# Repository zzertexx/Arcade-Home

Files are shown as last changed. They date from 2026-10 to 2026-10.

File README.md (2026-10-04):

# Arcade@Home
Console with games, outputting HDMI and Joysticks to control it

## What is it?
It is a combo of joysticks and main console which offers pixel games to play in multiplayer on any display with HDMI

## Why did I build it?
I saw that a lot of people did tamagotchi during their way, so I wanted to do similar but ended at gaming console 
I took my little bro with me to teach him hardware

## How to recreate it?
1. Order both PCBs
2. 3D Print enclosures
3. Assemble hardware
4. Flush Firmware(not ready yet)
5. Connect HDMI
6. Play!

## Future Plans:
* Enclosure for Joystick
* Firmware for ESP32
* Firmware for 

## Bill of Materials
| Name | Price |
| --- | --- |
| XUNPU HDMI-001S | 0.25$ |
| RP2350A | 1.3$ |
| JST 3 pin | 0.1$ |
| onsemi NCP1117 3.3V DPO | 0.25$ |
| Flash Memory W25Q128JVSIQ | 2.6$ |
| Tactile Button x2 | 0.04$ |
| Type C x2 | 1.5$ |
| Pi Radio Module 2 | 5.00$ |
| +1v1 buck | 0,4$ |
| Green LED 0603 x2 | 0.02$ |
| Header Pins | 0.15$ |
| SS34 | 0,03$ |
| 4.7uF 0603 x3 | 0.1$ |
| 100nF 0603 x14 | 0.12$ |
| 10uF 0805 x3 | 0.12$ |
| 15pF 0402 x2 | 0.04$ |
| 3.3uH 0806 | 0.3$ |
| 2.2uH | 0.1$ |
| 27R 0603 x2 | 0.00$ |
| 33R 0603 | 0.00$ |
| 5.1KR 0603 x2 | 0.00$ | 
| 220R x5 | 0.01$ |
| 270R 0603 x9 | 0.02$ |
| 1K 0603 x6 | 0.01$ |
| 1.2K | 0.01$ |
| 4.7K x2 | 0.01$ |
| 10K 0603 x2 | 0.01$ |
| 100R 0603 x3 | 0.00$ |
| 470R 0603 x2 | 0.01$ |
| 120K 0603 | 0.00$ | 
| 100K 0603 | 0.00$ | 
| Push Button x4 | 4.24$ |
| ESP32 - SuperMini | 2.00$ |
| Turn-ON Button | 1.3$ |
| Microswitch x4 | 2$ |
| TP4056 | 0.09$ |
| FS8205A | 0.06$ |
| DW01A | 0.03$ |
| Total | 8.6$ |

## Images



arcade_console (Assembly)

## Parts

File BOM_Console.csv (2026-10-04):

Arcade Console PCB
Name | Quantity | Price | Number | Link
XUNPU HDMI-001S | 1 | $0,25 | C720616 | https://www.lcsc.com/product-image/C720616.html?whichImg=sch
RP2350A | 1 | $1,30 | C42411118 | https://www.lcsc.com/product-detail/C42411118.html?s_z=n_q_t_rp2350
JST 3 pin TXM12M... | 1 | $0,10 | C284155 | https://www.lcsc.com/product-detail/C284155.html?s_z=n_q_12MHz%2520Crystal
onsemi NCP1117 3.3V DPO | 1 | $0,25 | C26537 | https://www.lcsc.com/product-detail/C26537.html
Flash Memory W25Q128JVSIQ | 1 | $2,60 | C97521 | https://www.lcsc.com/product-detail/C97521.html
Tactile Button | 2 | $0,04 | C53447020 | https://www.lcsc.com/product-detail/C53447020.html?s_z=n_q_tactile%2520button
Type C | 1 | $0,85 | C5409177 | https://www.lcsc.com/product-detail/C5409177.html
Pi Radio Module 2 | 1 | $5,00 |  | https://www.alibaba.com/product-detail/Raspberry-Pi-Original-Wireless-Module-Supports_1601564887233.html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
1v1 buck | 1 | $0,40 | C141836 | https://www.lcsc.com/product-detail/C141836.html?s_z=n_q_TLV62569%2520
Green LED 0603 | 2 | $0,02 | C7371905 | https://www.lcsc.com/product-detail/C7371905.html?s_z=n_q_t_LED
Header Pins | 1 | $0,15 | C2337 | https://www.lcsc.com/product-detail/C2337.html?s_z=n_q_t_pin%2520header
SS34 | 1 | $0,03 | C5380710 | https://www.lcsc.com/product-detail/C5380710.html?s_z=n_q_t_SS34
Capacitors
4.7uF 0603 | 3 | $0,10 | C20539423 | https://www.lcsc.com/product-detail/C20539423.html?s_z=n_q_t_CAPACITORS
100nF 0603 | 12 | $0,12 | C1590 | https://www.lcsc.com/product-detail/C1590.html?s_z=n_q_t_CAPACITORS
10uF 0805 | 2 | $0,12 | C15850 | https://www.lcsc.com/product-detail/C15850.html?s_z=n_q_t_CAPACITORS
15pF 0402 | 2 | $0,04 | C441742 | https://www.lcsc.com/product-detail/C441742.html?s_z=n_q_t_CAPACITORS
Inductor
3.3uH 0806 | 1 | $0,30 | C42411119 | https://www.lcsc.com/product-detail/C42411119.html
2.2uH | 1 | $0,10 | C7427146 | https://www.lcsc.com/product-detail/C7427146.html
Resistors
27 ohm 0603 | 2 | $0,00 | C2907021 | https://www.lcsc.com/product-detail/C2907021.html
33 ohm 0603 | 1 | $0,00 | C2909394 | https://www.lcsc.com/product-detail/C2909394.html
5.1K 0603 | 2 | $0,00 | C2907044 | https://www.lcsc.com/product-detail/C2907044.html
270R 0603 | 9 | $0,02 | C22966 | https://www.lcsc.com/product-detail/C22966.html
1K 0603 | 3 | $0,01 | C22548 | https://www.lcsc.com/product-detail/C22548.html
10K 0603 | 2 | $0,01 | C98220 | https://www.lcsc.com/product-detail/C98220.html
100R 0603 | 2 | $0,00 | C2906981 | https://www.lcsc.com/product-detail/C2906981.html
470R 0603 | 2 | $0,01 | C23179 | https://www.lcsc.com/product-detail/C23179.html
120K 0603 | 1 | $0,00 | C25808 | https://www.lcsc.com/product-detail/C25808.html
100K 0603 | 1 | $0,00 | C14675 | https://www.lcsc.com/product-detail/C14675.html

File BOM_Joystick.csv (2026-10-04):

ARCADE
Name | Quantity | Price | Link
Push Button | 4 | $4,24 | https://aliexpress.ru/item/1005008849653398.html?gatewayAdapt=glo2rus&sku_id=12000046936327681
Turn-ON Button | 1 | $1,30 | https://www.lcsc.com/product-detail/C48677982.html?s_z=n_q_t_BUTTON
4,7k resistor | 2 | $0,01 | https://www.lcsc.com/product-detail/C99782.html?s_z=n_q_t_resistor%2520
100nf capacitor | 2 | $0,02 | https://www.lcsc.com/product-detail/C14663.html?s_z=n_q_t_%2520Capacitors
10uf capacitor | 1 | $0,04 | https://www.lcsc.com/product-detail/C19702.html?s_z=n_q_t_%2520Capacitors
220 om resistor | 5 | $0,01 | https://www.lcsc.com/product-detail/C22962.html?s_z=n_q_t_resistor
1k resistor | 3 | $0,01 | https://www.lcsc.com/product-detail/C22548.html?s_z=n_q_t_resistor
100 resistor | 1 | $0,01 | https://www.lcsc.com/product-detail/C2906981.html?s_z=n_q_t_resistor
1,2k resistor | 1 | $0,01 | https://www.lcsc.com/product-detail/C114605.html?s_z=n_q_t_resistor
pin header 2,54mm | 1 |  | https://www.lcsc.com/product-detail/C2691448.html?s_z=n_q_t_pin%2520header%25202.54mm
Tp4056 | 1 | $0,09 | https://www.lcsc.com/product-detail/C725790.html?s_z=n_q_tp4056
fs8205A | 1 | $0,06 | https://www.lcsc.com/product-detail/C2830320.html?s_z=s_p_FS8205A
dw01A | 1 | $0,03 | https://www.lcsc.com/product-detail/C351410.html?s_z=s_p_DW01A
Type C | 1 | $0,90 | https://www.lcsc.com/product-detail/C5409177.html?s_z=s_p_10155435-00011LF
Microswitch(joystick) | 4 | $2,00 | https://www.alibaba.com/product-detail/Factory-High-quality-Micro-Switches-for_1601206239153.html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
ESP32-Supermini | 1 | $1,75 | https://aliexpress.ru/item/1005006685958843.html?sku_id=12000038011863174

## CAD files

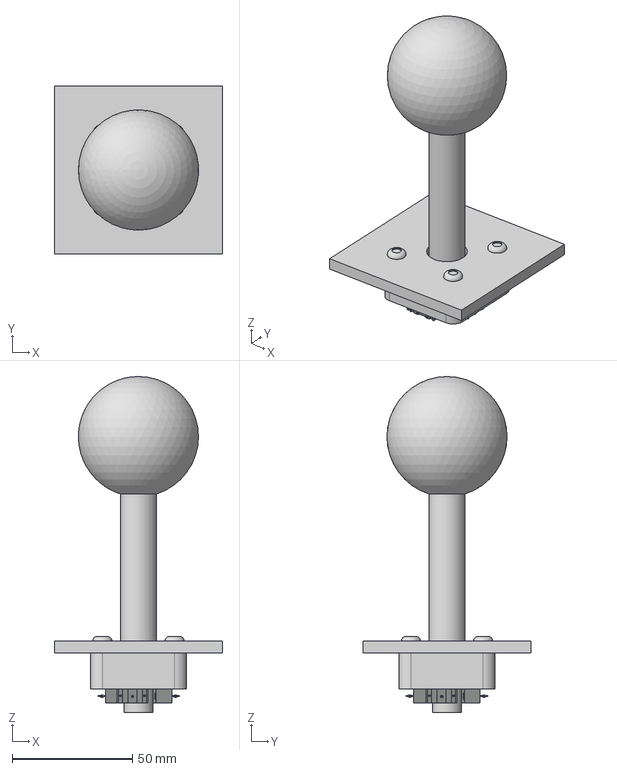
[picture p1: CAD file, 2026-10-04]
CAD/joystick.step
70.0 x 70.0 x 139.7 mm

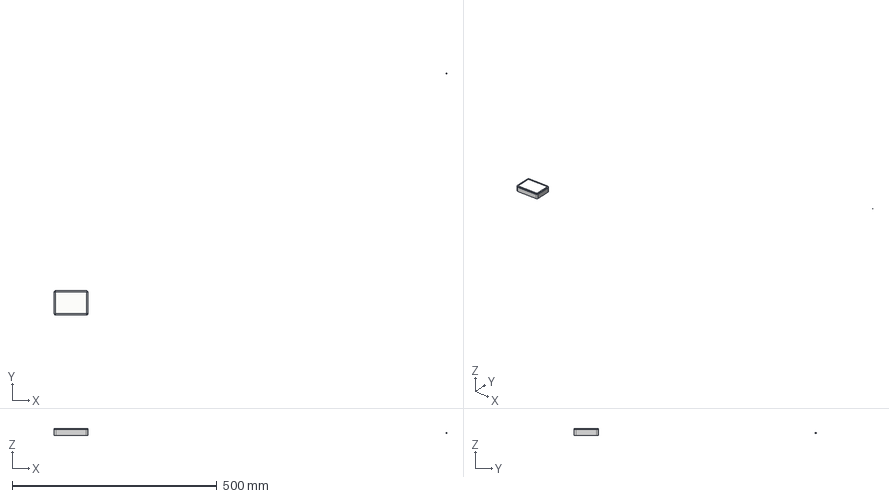
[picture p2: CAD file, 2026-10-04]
CAD/console.step
958.9 x 591.6 x 18.0 mm

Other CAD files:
CAD/console.f3z
CAD/joystick.f3z

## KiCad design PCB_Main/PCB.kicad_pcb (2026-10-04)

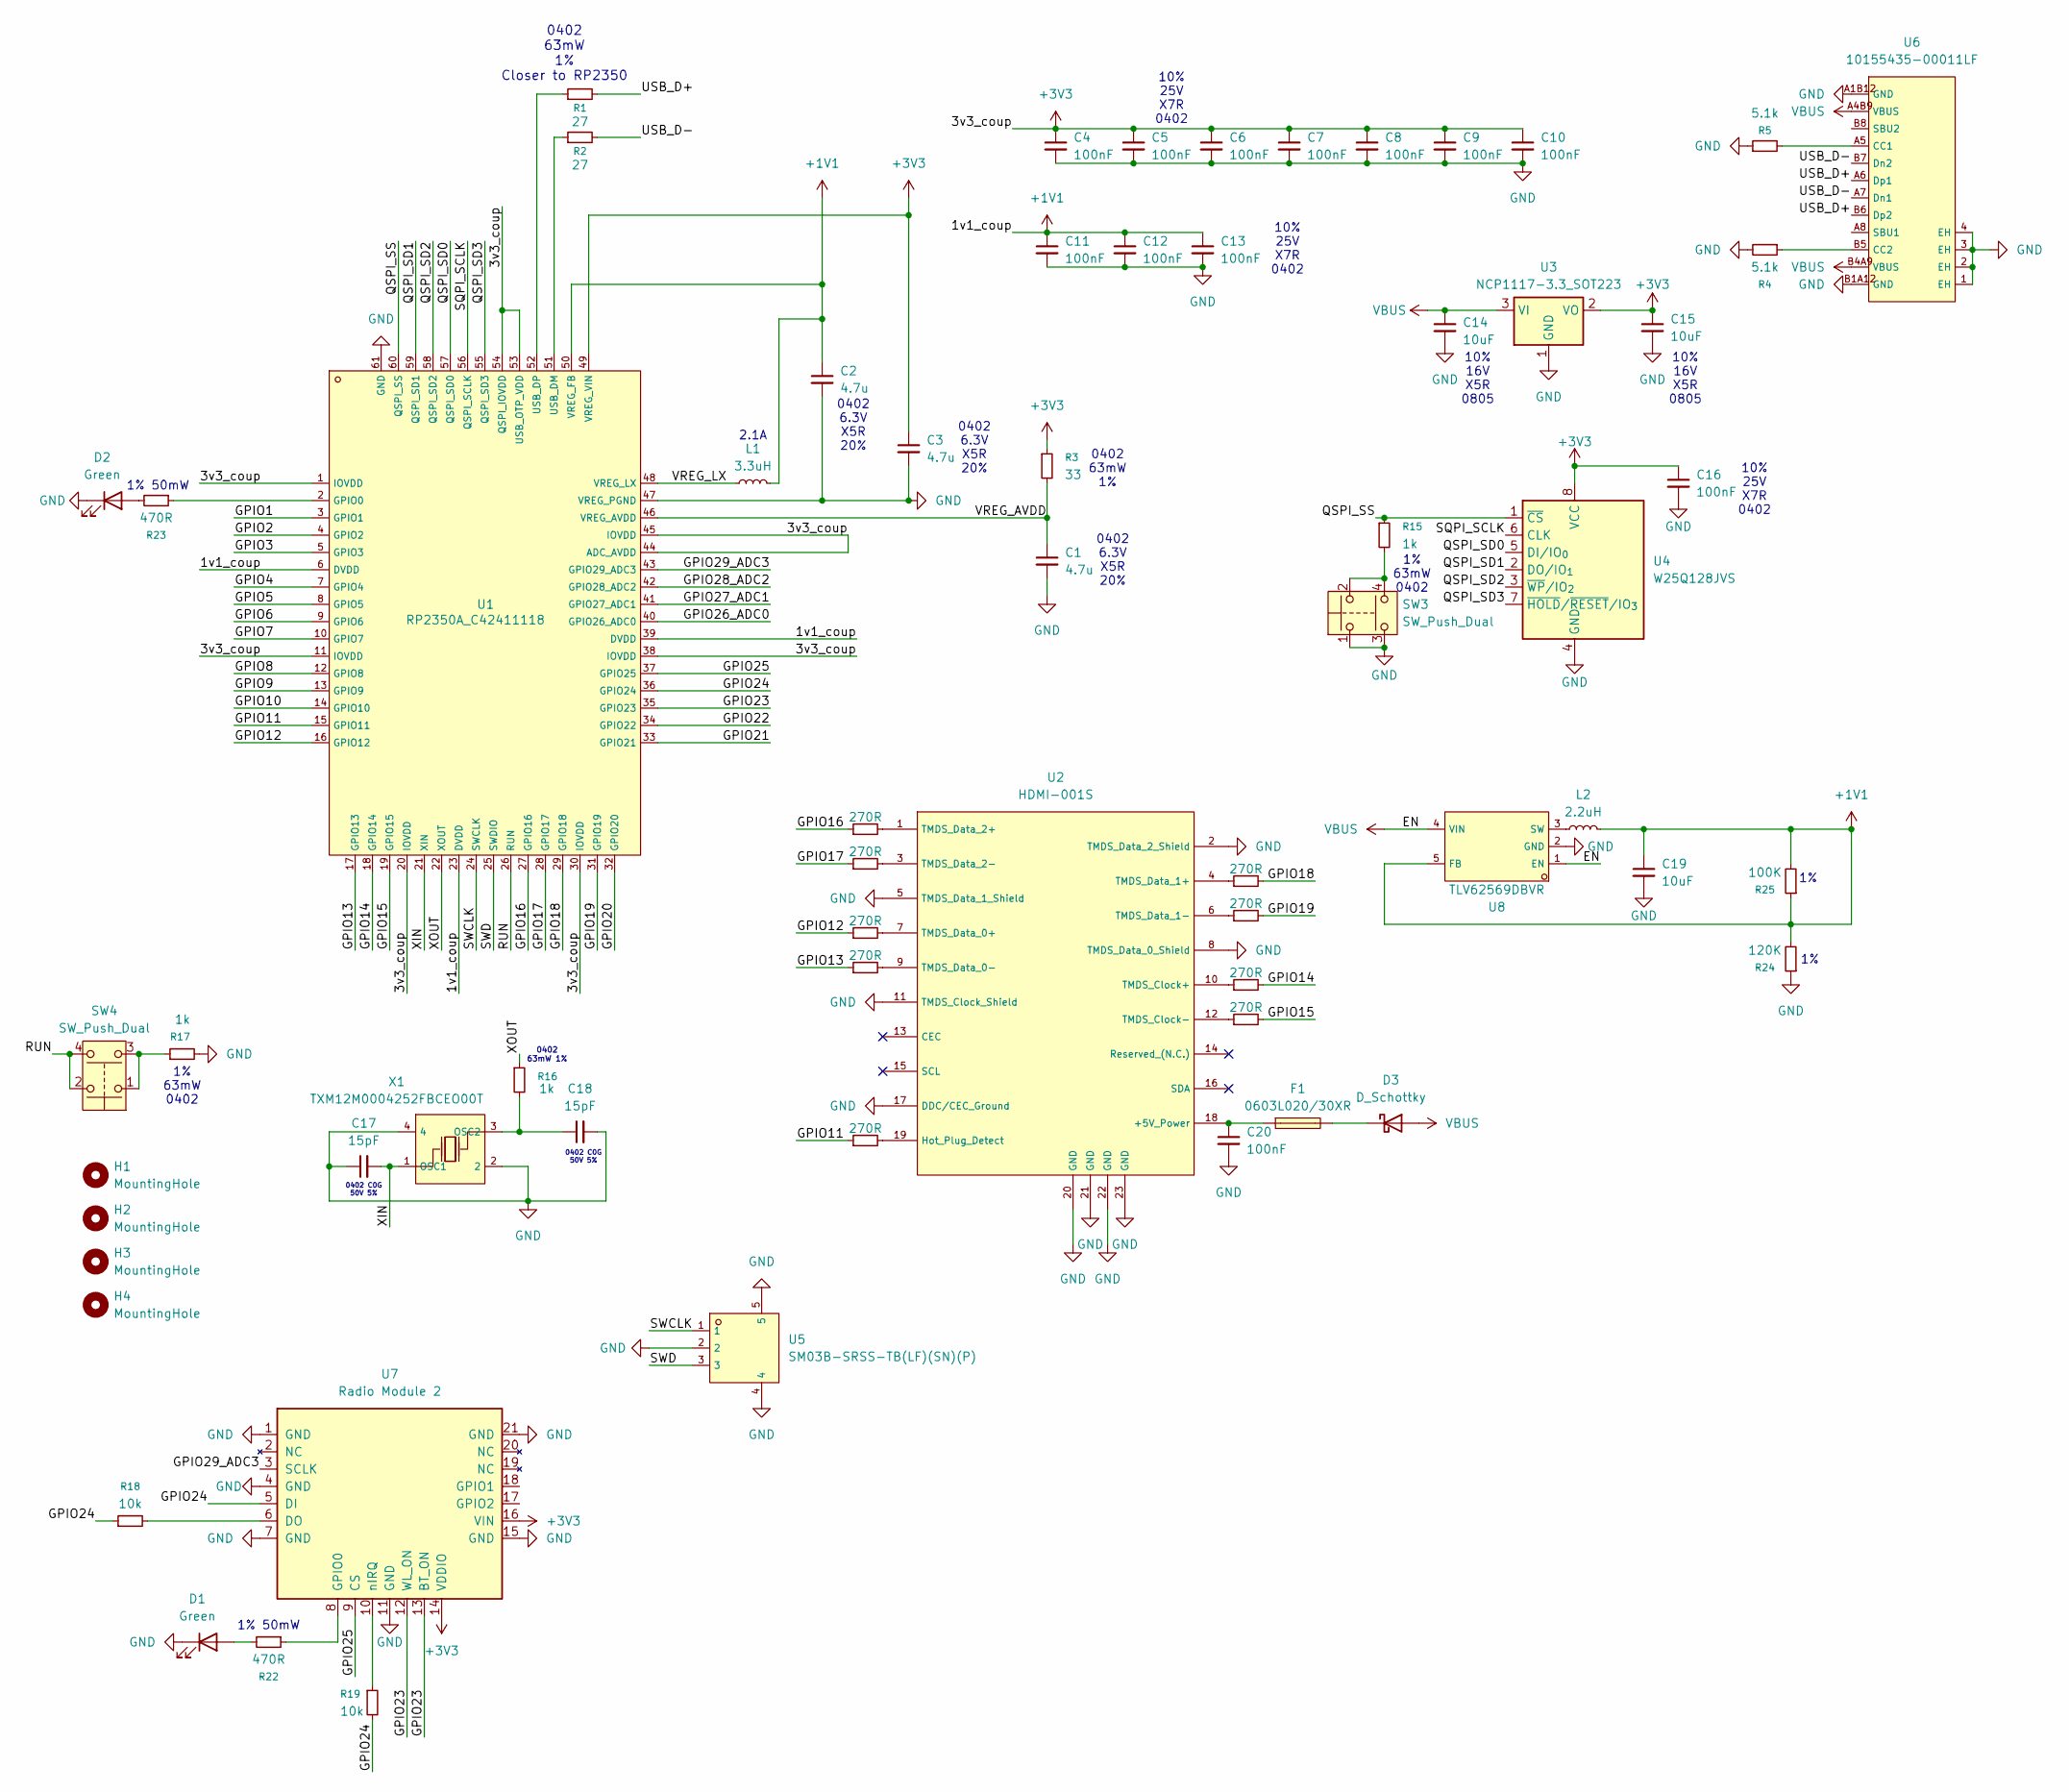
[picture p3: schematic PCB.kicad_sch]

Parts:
C1, C2, C3: 4.7u; C_0603_1608Metric_Pad1.08x0.95mm_HandSolder
C4, C5, C6, C7, C8, C9, C10, C11, C12, C13, C16, C20: 100nF; C_0603_1608Metric_Pad1.08x0.95mm_HandSolder
C14, C15, C19: 10uF; C_0805_2012Metric_Pad1.18x1.45mm_HandSolder
C17, C18: 15pF; C_0402_1005Metric_Pad0.74x0.62mm_HandSolder
D1, D2: Green; LED_0603_1608Metric_Pad1.05x0.95mm_HandSolder
D3: D_Schottky; D_SOD-123
F1: 0603L020/30XR; F0603; LCSC C20608677
H1, H2, H3, H4: MountingHole; MountingHole_2.5mm
L1: 3.3uH; IND-SMD_L2.0-W1.6_AOTA-B201610S3R3-101-T
L2: 2.2uH; L_APV_ANR6028
R1, R2: 27; R_0603_1608Metric_Pad0.98x0.95mm_HandSolder
R3: 33; R_0603_1608Metric_Pad0.98x0.95mm_HandSolder
R4, R5: 5.1k; R_0603_1608Metric_Pad0.98x0.95mm_HandSolder
R6, R7, R8, R9, R10, R11, R12, R13, R14: 270R; R_0603_1608Metric_Pad0.98x0.95mm_HandSolder
R15, R16, R17: 1k; R_0603_1608Metric_Pad0.98x0.95mm_HandSolder
R18, R19: 10k; R_0603_1608Metric_Pad0.98x0.95mm_HandSolder
R22, R23: 470R; R_0603_1608Metric_Pad0.98x0.95mm_HandSolder
R24: 120K; R_0603_1608Metric_Pad0.98x0.95mm_HandSolder
R25: 100K; R_0603_1608Metric_Pad0.98x0.95mm_HandSolder
SW3, SW4: SW_Push_Dual; SW-SMD_4P-L6.0-W6.0-P4.50-LS7.2
U1: RP2350A_C42411118; QFN-60_L7.0-W7.0-P0.40-TL-EP3.4; LCSC C42411118
U2: HDMI-001S; HDMI-SMD_HDMI-001S; LCSC C720616
U3: NCP1117-3.3_SOT223; SOT-223-3_TabPin2
U4: W25Q128JVS; SOIC-8_5.3x5.3mm_P1.27mm
U5: SM03B-SRSS-TB(LF)(SN)(P); CONN-SMD_SM03B-SRSS-TB-LF-SN-P; LCSC C160403
U6: 10155435-00011LF; USB-C-SMD_10155435-00011LF; LCSC C5409177
U7: Radio Module 2; rpi_rmc20452t
U8: TLV62569DBVR; SOT-23-5_L3.0-W1.7-P0.95-LS2.8-BR; LCSC C141836
X1: TXM12M0004252FBCEO00T; OSC-SMD_4P-L2.5-W2.0-BL; LCSC C284155

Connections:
+1V1: C2.1, C11.1, C12.1, C13.1, C19.1, L1.2, L2.2, R24.2, R25.1, R25.2, U1.6 (DVDD), U1.23 (DVDD), U1.39 (DVDD), U1.50 (VREG_FB), U8.5 (FB)
+3V3: C3.1, C4.1, C5.1, C6.1, C7.1, C8.1, C9.1, C10.1, C15.1, C16.1, R3.1, U1.1 (IOVDD), U1.11 (IOVDD), U1.20 (IOVDD), U1.30 (IOVDD), U1.38 (IOVDD), U1.44 (ADC_AVDD), U1.45 (IOVDD), U1.49 (VREG_VIN), U1.53 (USB_OTP_VDD), U1.54 (QSPI_IOVDD), U3.2 (VO), U4.8 (VCC), U7.14 (VDDIO), U7.16 (VIN)
/GPIO1: U1.3 (GPIO1)
/GPIO2: U1.4 (GPIO2)
/GPIO3: U1.5 (GPIO3)
/GPIO4: U1.7 (GPIO4)
/GPIO5: U1.8 (GPIO5)
/GPIO6: U1.9 (GPIO6)
/GPIO7: U1.10 (GPIO7)
/GPIO8: U1.12 (GPIO8)
/GPIO9: U1.13 (GPIO9)
/GPIO10: U1.14 (GPIO10)
/GPIO11: R14.1, U1.15 (GPIO11)
/GPIO12: R10.1, U1.16 (GPIO12)
/GPIO13: R11.1, U1.17 (GPIO13)
/GPIO14: R12.2, U1.18 (GPIO14)
/GPIO15: R13.2, U1.19 (GPIO15)
/GPIO16: R6.1, U1.27 (GPIO16)
/GPIO17: R7.1, U1.28 (GPIO17)
/GPIO18: R8.2, U1.29 (GPIO18)
/GPIO19: R9.2, U1.31 (GPIO19)
/GPIO20: U1.32 (GPIO20)
/GPIO21: U1.33 (GPIO21)
/GPIO22: U1.34 (GPIO22)
/GPIO23: U1.35 (GPIO23), U7.12 (WL_ON), U7.13 (BT_ON)
/GPIO24: R18.1, R19.2, U1.36 (GPIO24), U7.5 (DI)
/GPIO25: U1.37 (GPIO25), U7.9 (CS)
/GPIO26_ADC0: U1.40 (GPIO26_ADC0)
/GPIO27_ADC1: U1.41 (GPIO27_ADC1)
/GPIO28_ADC2: U1.42 (GPIO28_ADC2)
/GPIO29_ADC3: U1.43 (GPIO29_ADC3), U7.3 (SCLK)
/QSPI_SD0: U1.57 (QSPI_SD0), U4.5 (DI/IO_{0})
/QSPI_SD1: U1.59 (QSPI_SD1), U4.2 (DO/IO_{1})
/QSPI_SD2: U1.58 (QSPI_SD2), U4.3 (~WP/IO_{2})
/QSPI_SD3: U1.55 (QSPI_SD3), U4.7 (~HOLD/~RESET/IO_{3})
/QSPI_SS: R15.1, U1.60 (QSPI_SS), U4.1 (~CS)
/RUN: SW4.2, SW4.4, U1.26 (RUN)
/SQPI_SCLK: U1.56 (QSPI_SCLK), U4.6 (CLK)
/SWCLK: U1.24 (SWCLK), U5.1
/SWD: U1.25 (SWDIO), U5.3
/USB_D+: R1.2, U6.A6 (Dp1), U6.B6 (Dp2)
/USB_D-: R2.2, U6.A7 (Dn1), U6.B7 (Dn2)
/VREG_AVDD: C1.1, R3.2, U1.46 (VREG_AVDD)
/VREG_LX: L1.1, U1.48 (VREG_LX)
/XIN: C17.2, U1.21 (XIN), X1.1 (OSC1)
/XOUT: R16.1, U1.22 (XOUT)
GND: C1.2, C2.2, C3.2, C4.2, C5.2, C6.2, C7.2, C8.2, C9.2, C10.2, C11.2, C12.2, C13.2, C14.2, C15.2, C16.2, C17.1, C18.2, C19.2, C20.2, D1.1 (K), D2.1 (K), R4.2, R5.1, R17.2, R24.1, SW3.1, SW3.3, U1.47 (VREG_PGND), U1.61 (GND), U2.2 (TMDS_Data_2_Shield), U2.5 (TMDS_Data_1_Shield), U2.8 (TMDS_Data_0_Shield), U2.11 (TMDS_Clock_Shield), U2.17 (DDC/CEC_Ground), U2.20 (GND), U2.21 (GND), U2.22 (GND), U2.23 (GND), U3.1 (GND), U4.4 (GND), U5.2, U5.4, U5.5, U6.1 (EH), U6.2 (EH), U6.3 (EH), U6.4 (EH), U6.A1B12 (GND), U6.B1A12 (GND), U7.1 (GND), U7.4 (GND), U7.7 (GND), U7.11 (GND), U7.15 (GND), U7.21 (GND), U8.2 (GND), X1.2, X1.4
unnamed: D1.2 (A), R22.2
unnamed: D2.2 (A), R23.2
unnamed: D3.1 (K), F1.2
unnamed: R15.2, SW3.2, SW3.4
unnamed: R17.1, SW4.1, SW4.3
unnamed: R23.1, U1.2 (GPIO0)
unnamed: R2.1, U1.51 (USB_DM)
unnamed: R1.1, U1.52 (USB_DP)
unnamed: C20.1, F1.1, U2.18 (+5V_Power)
unnamed: R14.2, U2.19 (Hot_Plug_Detect)
unnamed: R12.1, U2.10 (TMDS_Clock+)
unnamed: R13.1, U2.12 (TMDS_Clock-)
unnamed: R10.2, U2.7 (TMDS_Data_0+)
unnamed: R11.2, U2.9 (TMDS_Data_0-)
unnamed: R8.1, U2.4 (TMDS_Data_1+)
unnamed: R9.1, U2.6 (TMDS_Data_1-)
unnamed: R6.2, U2.1 (TMDS_Data_2+)
unnamed: R7.2, U2.3 (TMDS_Data_2-)
unnamed: R5.2, U6.A5 (CC1)
unnamed: R4.1, U6.B5 (CC2)
unnamed: R18.2, U7.6 (DO)
unnamed: R22.1, U7.8 (GPIO0)
unnamed: R19.1, U7.10 (nIRQ)
unnamed: L2.1, U8.3 (SW)
unnamed: C18.1, R16.2, X1.3 (OSC2)
VBUS: C14.1, D3.2 (A), U3.3 (VI), U6.A4B9 (VBUS), U6.B4A9 (VBUS), U8.1 (EN), U8.4 (VIN)

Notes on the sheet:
0402 63mW 1% Closer to RP2350
1% 50mW
0402 6.3V X5R 20%
10% 16V X5R 0805
0402 63mW 1%
10% 25V X7R 0402
0402 63mW 1%
1% 63mW 0402
0402 C0G 50V 5%
2.1A

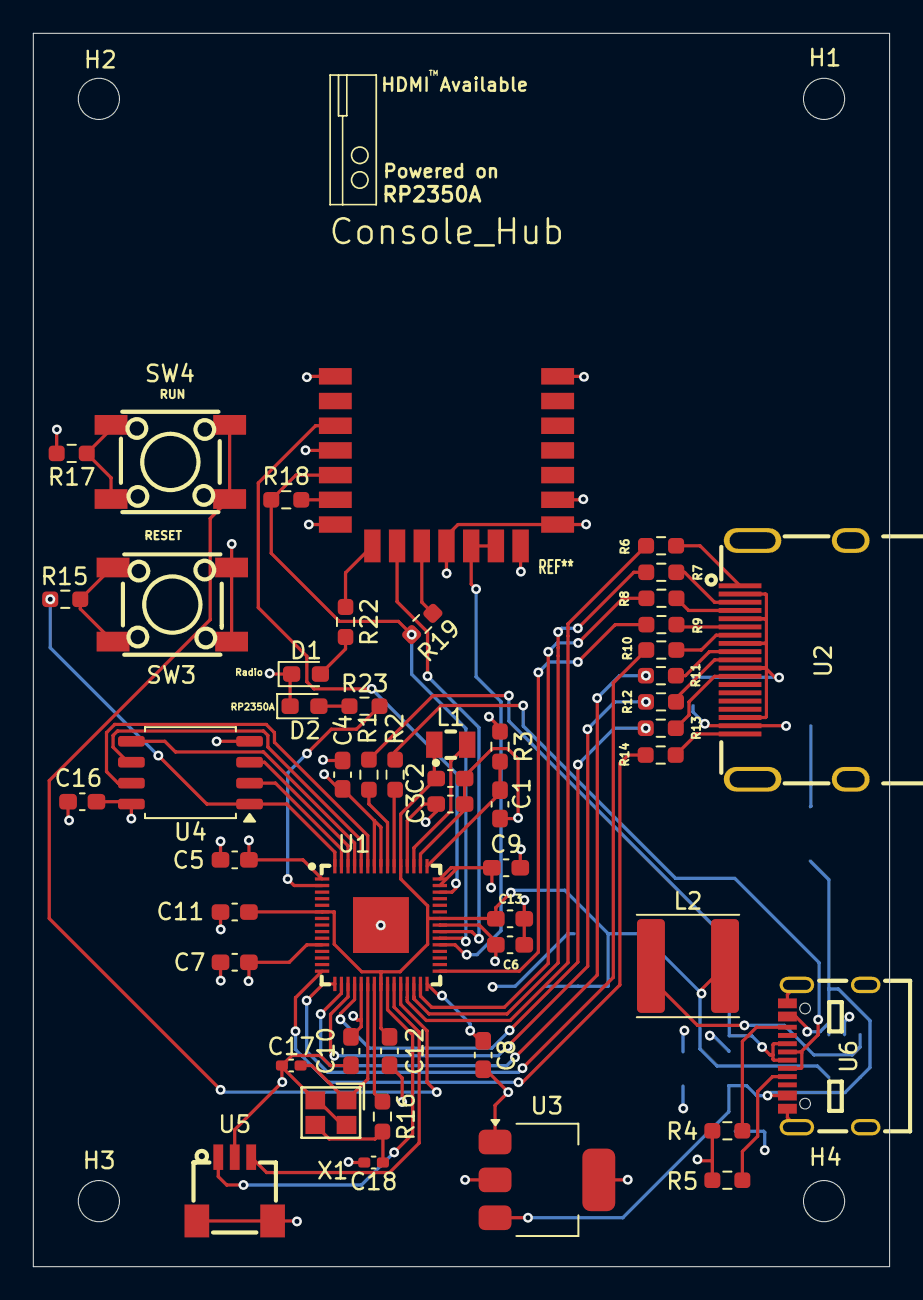
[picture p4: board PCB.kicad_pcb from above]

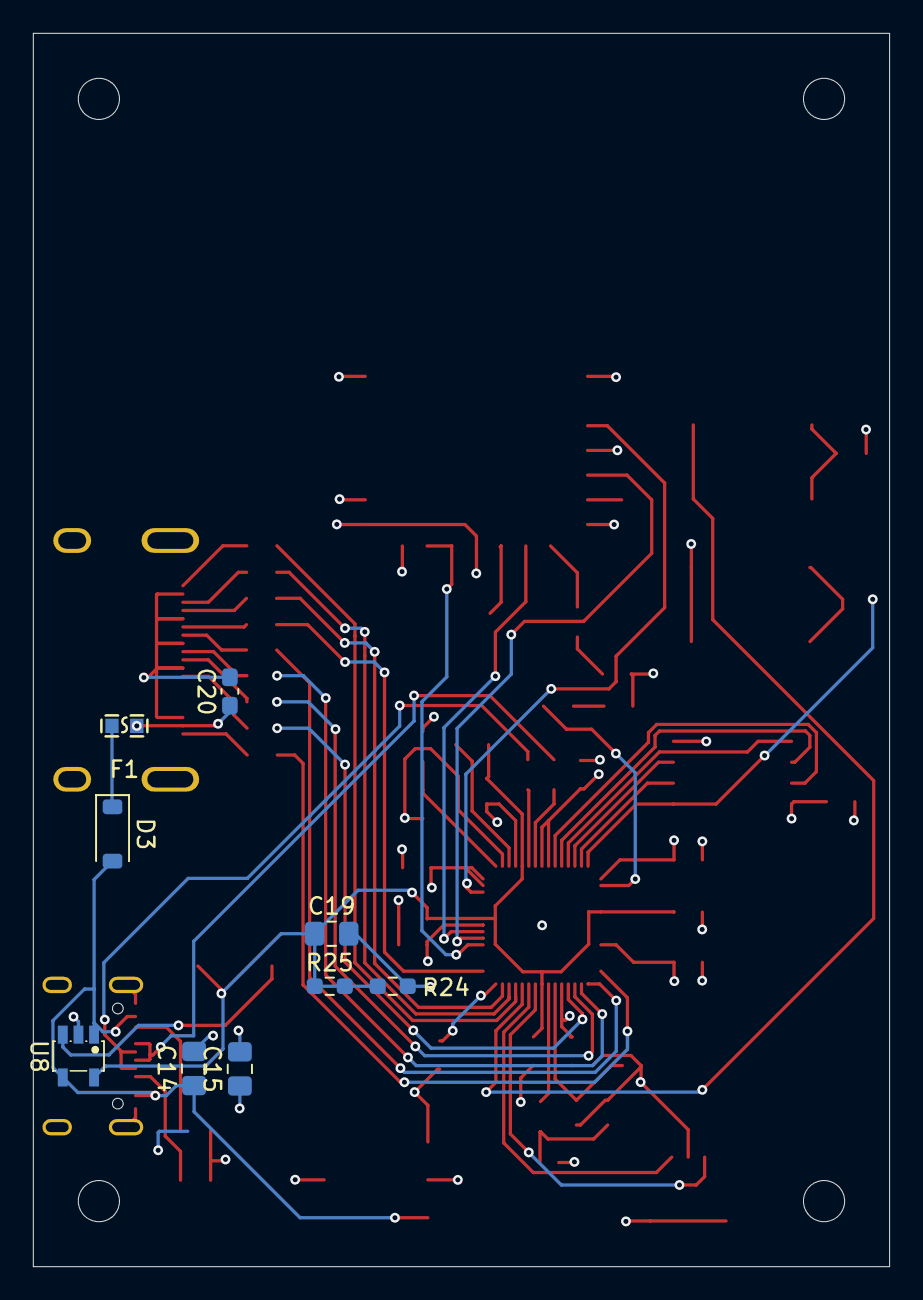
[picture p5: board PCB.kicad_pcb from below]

Board: 4 copper layers, 52.0 x 74.9 mm, 64 parts (9 on the bottom side), 57 nets.

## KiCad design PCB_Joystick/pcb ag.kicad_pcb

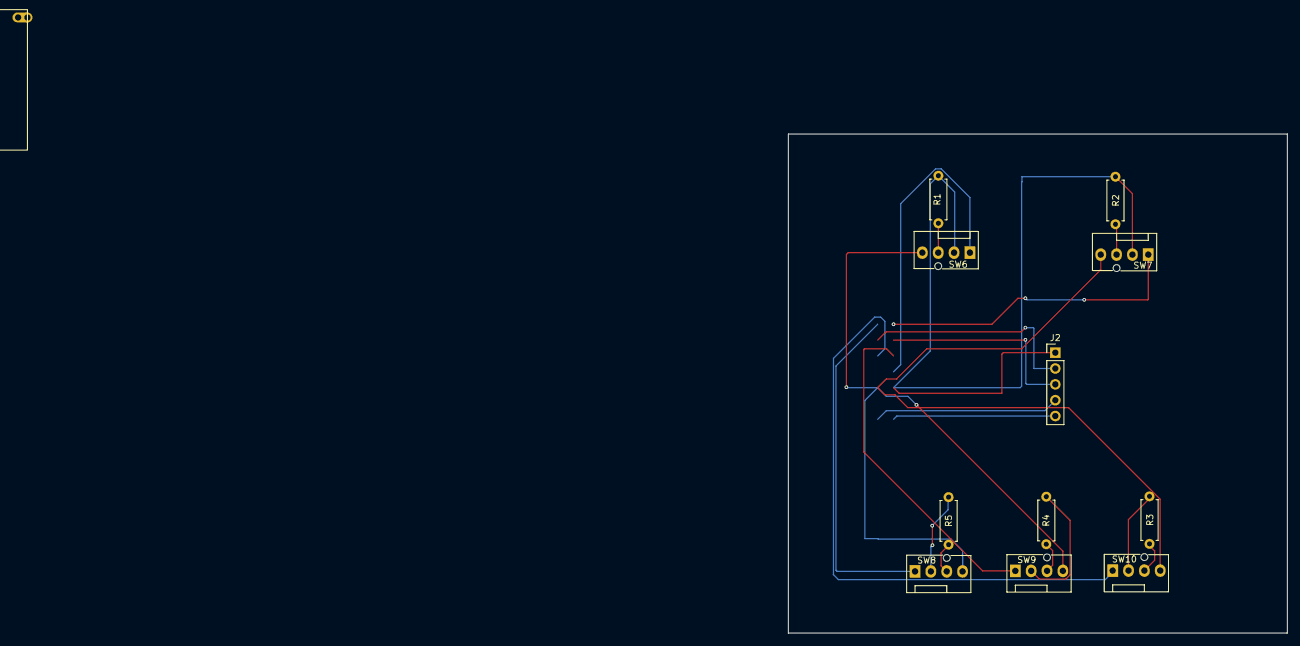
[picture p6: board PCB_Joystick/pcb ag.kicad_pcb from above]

Board: 2 copper layers, 80.0 x 80.0 mm, 12 parts (0 on the bottom side), 8 nets.

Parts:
J2: Conn_01x05; PinHeader_1x05_P2.54mm_Vertical
R1, R2: 220ом; R_Axial_DIN0207_L6.3mm_D2.5mm_P7.62mm_Horizontal
R3, R4, R5: 220; R_Axial_DIN0207_L6.3mm_D2.5mm_P7.62mm_Horizontal
SW6, SW7, SW8, SW9, SW10: SW_Push_LED; FanPinHeader_1x04_P2.54mm_Vertical
U1: ESP32-C3-Supermini

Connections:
+3V3: SW6.4 (A), SW7.4 (A), SW8.4 (A), SW9.4 (A), SW10.4 (A)
/2button.gpio6: SW7.1, U1.1 (GPIO6_1)
GND: J2.1, R1.2, R2.2, R3.2, R4.2, R5.2, SW6.2, SW7.2, SW8.2, SW9.2, SW10.2
unnamed: R1.1, SW6.3 (K)
unnamed: R2.1, SW7.3 (K)
unnamed: R5.1, SW8.3 (K)
unnamed: R4.1, SW9.3 (K)
unnamed: R3.1, SW10.3 (K)

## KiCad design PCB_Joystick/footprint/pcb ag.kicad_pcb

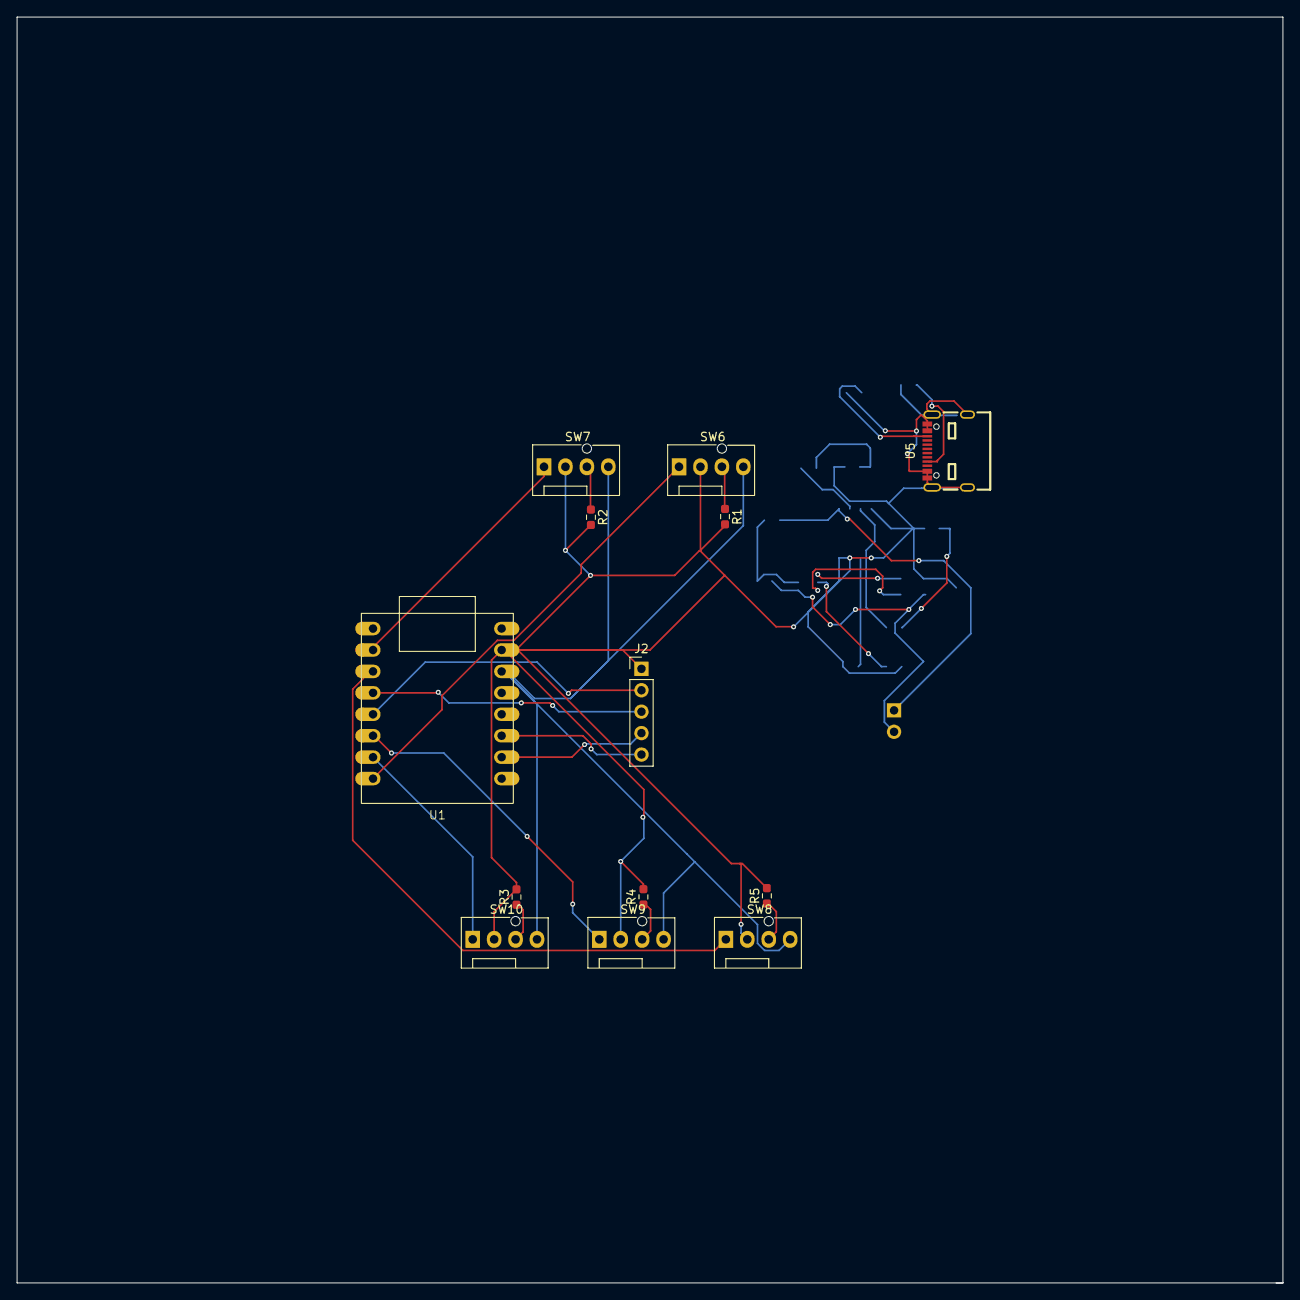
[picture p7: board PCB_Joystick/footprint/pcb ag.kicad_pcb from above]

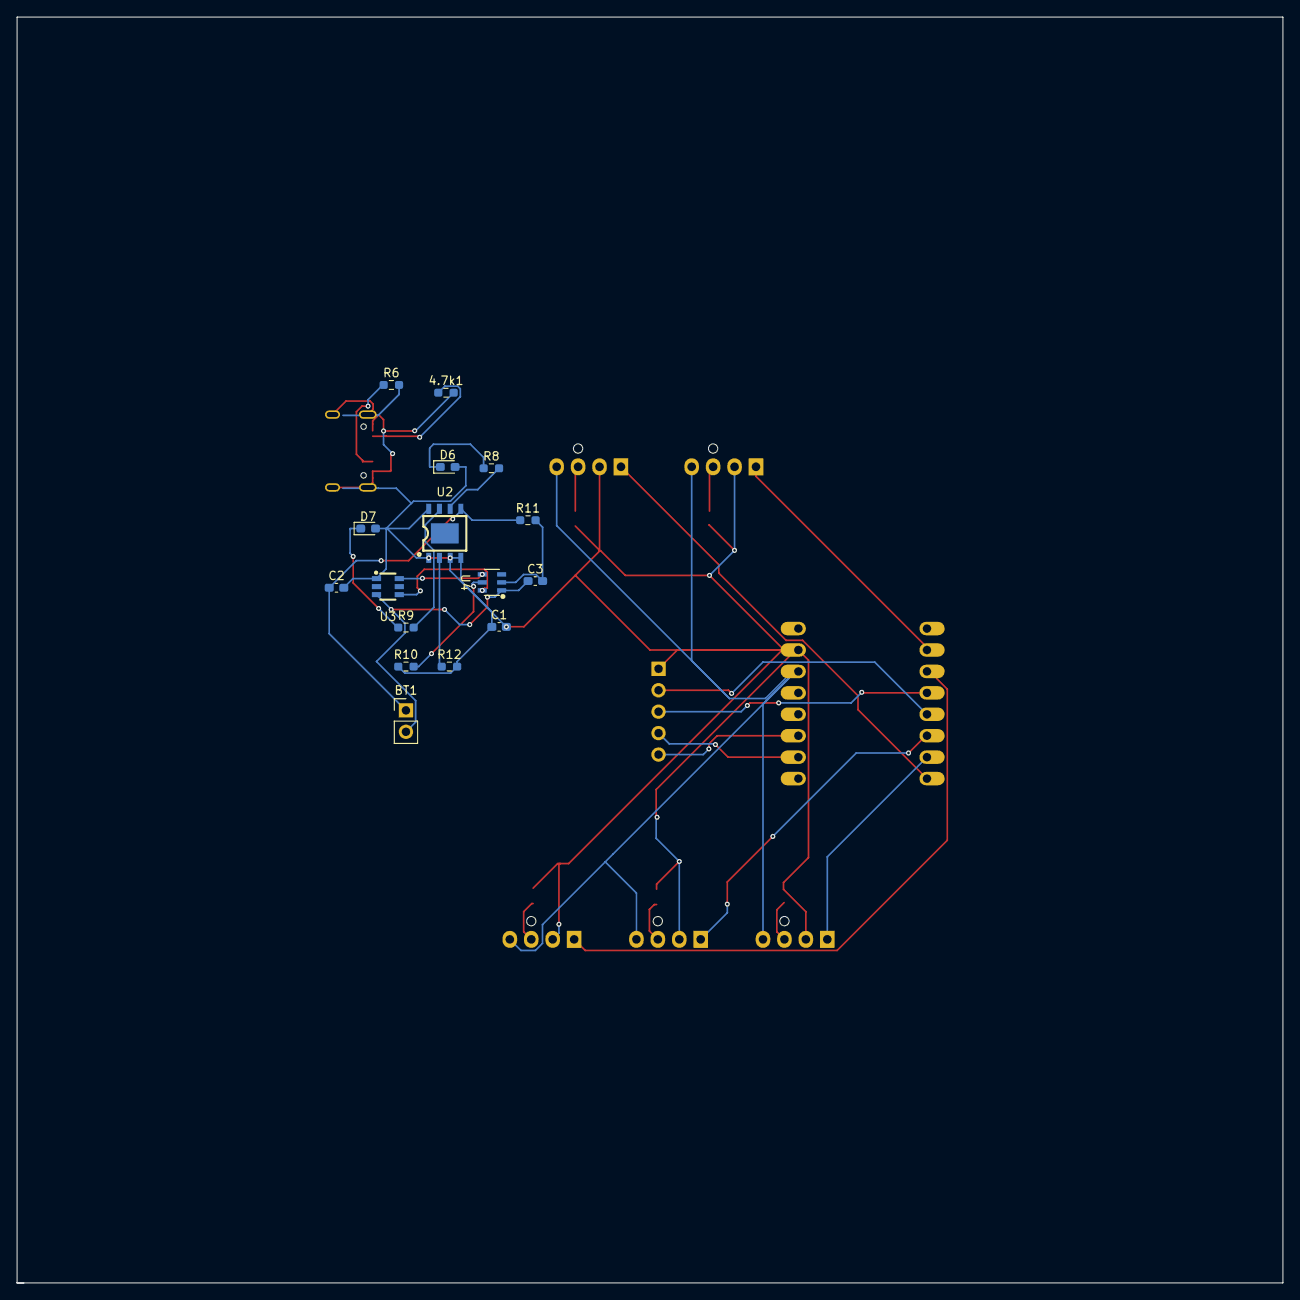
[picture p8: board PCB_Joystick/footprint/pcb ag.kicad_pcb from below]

Board: 2 copper layers, 150.0 x 150.0 mm, 29 parts (16 on the bottom side), 29 nets.

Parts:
4.7k1: R; R_0603_1608Metric_Pad0.98x0.95mm_HandSolder
BT1: Battery; PinHeader_1x02_P2.54mm_Vertical
C1, C3: 0.1uF; C_0603_1608Metric_Pad1.08x0.95mm_HandSolder
C2: 10uF; C_0603_1608Metric_Pad1.08x0.95mm_HandSolder
D6: GREEN; LED_0603_1608Metric_Pad1.05x0.95mm_HandSolder
D7: RED; LED_0603_1608Metric_Pad1.05x0.95mm_HandSolder
J2: Conn_01x05; PinHeader_1x05_P2.54mm_Vertical
R1, R2: 220ом; R_0603_1608Metric_Pad0.98x0.95mm_HandSolder
R3, R4, R5: 220; R_0603_1608Metric_Pad0.98x0.95mm_HandSolder
R6: 4.7k; R_0603_1608Metric_Pad0.98x0.95mm_HandSolder
R8, R9, R10: 1k; R_0603_1608Metric_Pad0.98x0.95mm_HandSolder
R11: 100; R_0603_1608Metric_Pad0.98x0.95mm_HandSolder
R12: 1.2k; R_0603_1608Metric_Pad0.98x0.95mm_HandSolder
SW6, SW7, SW8, SW9, SW10: SW_Push_LED; FanPinHeader_1x04_P2.54mm_Vertical
U1: ESP32-C3-Supermini
U2: TP4056-42-ESOP8; ESOP-8_L4.9-W3.9-P1.27-LS6.0-BL-EP
U3: FS8205A_C2830320; SOT-23-6_L2.9-W1.6-P0.95-LS2.8-BR
U4: DW01A_C351410; SOT-23-6_L2.9-W1.6-P0.95-LS2.8-BL
U5: 10155435-00011LF; USB-C-SMD_10155435-00011LF

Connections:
+3V3: SW6.4 (A), SW7.4 (A), SW8.4 (A), SW9.4 (A), SW10.4 (A), U1.10 (3.3V)
/1button.gpio5: SW6.1, U1.7 (GPIO21)
/2.2button.gpio9: J2.2, U1.4 (GPIO9)
/2button.gpio6: SW7.1, U1.1 (GPIO6)
/3.2button.gpio0: J2.3, U1.3 (GPIO8)
/3button.gpio7: SW8.1, U1.2 (GPIO7)
/4.2button.gpio1: J2.4, U1.14 (GPIO1)
/4button.gpio10: SW9.1, U1.5 (GPIO10)
/5.2button.gpio2: J2.5, U1.13 (GPIO2)
/5button.gpio20: SW10.1, U1.6 (GPIO20)
/VBAT+: BT1.1 (+), C2.1, R11.1, U2.5 (BAT)
GND: 4.7k1.2, C1.1, C1.2, C2.2, D6.2 (A), D7.2 (A), J2.1, R1.2, R2.2, R3.2, R4.2, R5.2, R6.2, R10.1, R12.2, SW6.2, SW7.2, SW8.2, SW9.2, SW10.2, U1.9 (GND), U2.1 (TEMP), U2.3 (GND), U2.4 (V_{CC}), U2.8 (CE), U3.1 (S1), U5.1 (EH), U5.2 (EH), U5.3 (EH), U5.4 (EH), U5.A1B12 (GND), U5.A4B9 (VBUS), U5.B1A12 (GND), U5.B4A9 (VBUS)
unnamed: BT1.2 (-), C3.1, U3.3 (S2), U4.1 (OD)
unnamed: D6.1 (K), R8.1
unnamed: D7.1 (K), R9.1
unnamed: R1.1, SW6.3 (K)
unnamed: R2.1, SW7.3 (K)
unnamed: R5.1, SW8.3 (K)
unnamed: R4.1, SW9.3 (K)
unnamed: R3.1, SW10.3 (K)
unnamed: R12.1, U2.2 (PROG)
unnamed: R9.2, U2.7 (~CHRG)
unnamed: R8.2, U2.6 (~STDBY)
unnamed: U3.6 (G1), U4.4 (TD)
unnamed: U3.4 (G2), U4.6 (GND)
unnamed: R10.2, U4.5 (VCC)
unnamed: C3.2, R11.2, U4.2 (VM)
unnamed: R6.1, U5.A5 (CC1)
unnamed: 4.7k1.1, U5.B5 (CC2)

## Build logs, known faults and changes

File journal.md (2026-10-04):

---
title: "Arcade at Home"
author: "Alimzhan"
description: "Gaming Console with Joysticks and Main Hub"
created_at: "2026-27-09"
---

# September 24: Components

Helped my team with creating footprint
Researched RP2350


**Total time spent: 1h:50**

# September 25: Schematics

Started working on schematics



**Total time spent: 2h:30min**

# September 26: Started Bill of Materials

More work on schematics and addition of BOM



**Total time spent: 2h:30min**

# September 27: Addition of wireless

More work on schematics, specifically addition of wireless hardware CYW43439



**Total time spent: 3h:30min**

# September 29: Change of wireless system

Found more easier way - Radio Module 2
In CYW43439 needed to setup antenna, crystal, memory externally, while RM2 had all inside abstractly with less pinout



**Total time spent: 1h**

# September 30: Getting closer to PCB design

Finished schematics and almost done assigning footprints



**Total time spent: 1h:30min**

# October 1: Started PCB design

Finally done with schematics and started placing footprints for PCB design



**Total time spent: 2h:35min**

# October 2: More work on PCB design

Almost done with designing PCB



**Total time spent: 2h:50min**

# October 4: 3D ecnlosure

Did enclosure for console



**Total time spent: 1h:30min**

---
title: "Arcade at Home"
author: "Amir"
description: "Gaming Console with Joysticks and Main Hub"
created_at: "2026-27-09"
---

# September 21: first idea

do first idea of pcb 



**Total time spent: 1h:05**

# September 22: search

search microcontrolrer



**Total time spent: 30min**

# September 23 : second idea

did second idea of pcb 
search microcontroler



# September 24: fix 

 fixing pcb 
 search microcontroler
 third idea of pcb

 

# September 25: fix mistakes

fixing mistakes



# September 26: pcb desing 

start do pcb desing 



# September 27: pcb desing finish

finish do pcb desing 
plus buttery



# September 28: pcb shematic plus buttery

 did pcb chematic buttery 
 try to understand what i did

 

  # September 29:finish buttery pcb chematic

  finish chematic 
  start pcb buttery desing 

  

 # September 30: buttery's pcb desing 

 aded some footprints 
 pcb desing 

 

  # October 01: fill bill of materials

  fill bill of  materials
  pcb desing 

  

  # October 02: fix mistakes

  fix mistakes in chematic and desing 
  


  # October 03:3D desing try

  try do 3D desing but it was sooo hard to do

  

  # October 04: try a lot 3D desing 

  do a lot mistakes in 3d 
 learn how to do 3D desing but it was very hard and i do a lot of different version 



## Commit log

2026-09-27 console PCB
    [PCB.kicad_pcb, PCB.kicad_sch, PCB.recovered.2026-09-27_200230.kicad_sch]
2026-09-27 Update journal with September entries and details
    Added journal entries for September 21 to 27, detailing PCB design ideas, searches, and fixes.
2026-10-04 u;pd
    Added detailed entries for PCB design progress, including images and notes on each day's activities.
